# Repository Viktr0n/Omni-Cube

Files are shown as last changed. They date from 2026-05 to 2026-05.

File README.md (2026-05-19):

# Omni-Cube

## Project Overview

The Omni-Cube is a gaming console with an omnidirectional Andotrope display. It is a final thesis project for upper secondary school that addresses the challenge of restricted viewing angles in traditional multiplayer gaming by providing a 360-degree display experience.

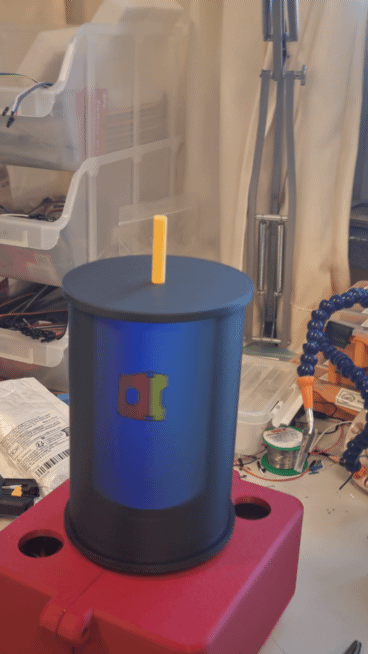
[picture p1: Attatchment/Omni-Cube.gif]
Omni-Cube
 
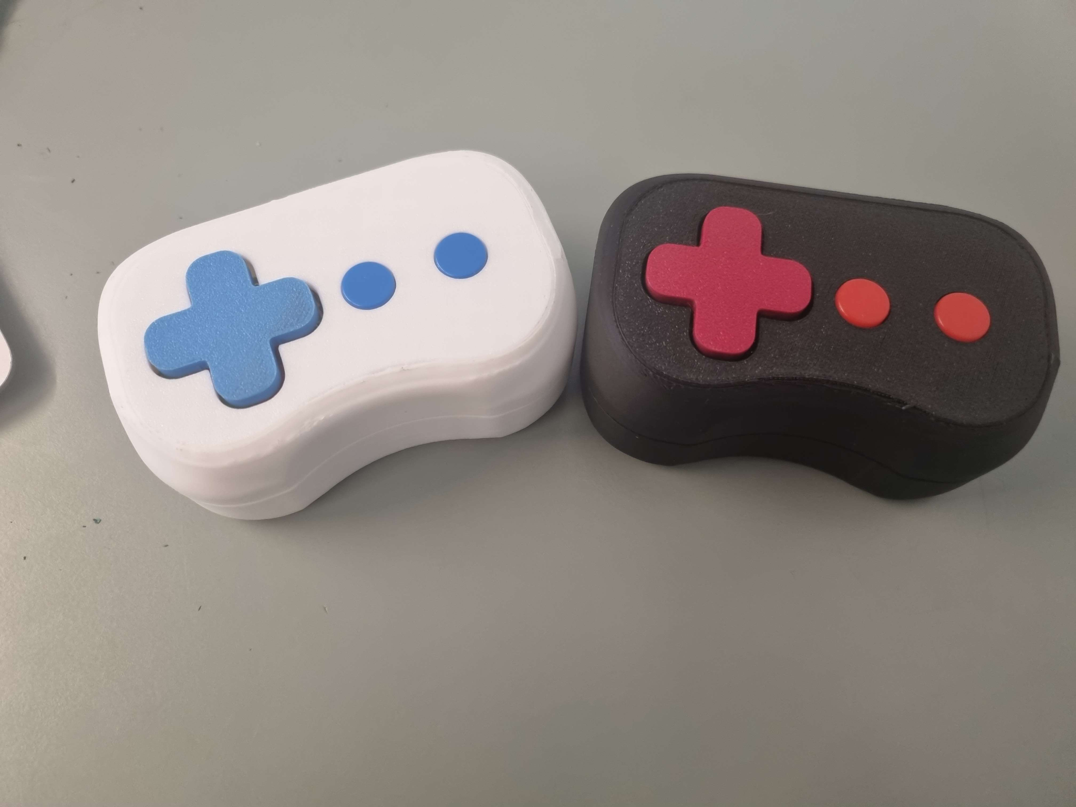
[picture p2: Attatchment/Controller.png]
Controller

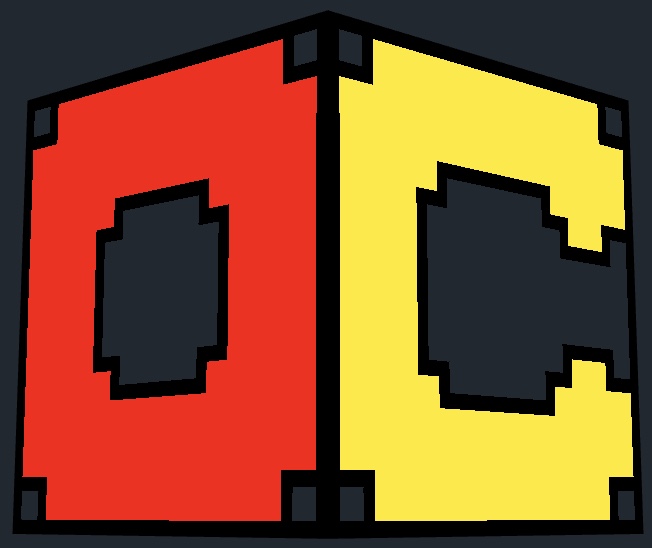
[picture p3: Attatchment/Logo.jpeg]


## Hardware Components

- **Main Console**: Raspberry Pi 3 Model B running CircuitPython
- **Display**: RA8875 omnidirectional display with 360-degree image capability
- **Controllers**: Two handheld wireless controllers built with ESP32/ESP32-S3 using Bluetooth Low Energy (BLE)
- **Motor Control**: H-bridge controlled DC motor for display rotation
- **Chassis**: Custom 3D-printed PLA housing designed in Fusion 360

## Software Structure

- **OC_splashscreen.py** - Splash screen with project title and creator credits
- **OC_main_menu.py** - Main menu system with game selection and power control
- **OC_pong.py** - Pong game implementation with BLE controller support
- **OC_motorCode.py** - Motor control via PWM and GPIO
- **OC_controller_plr1.ino & OC_controller_plr2.ino** - Wireless controller firmware with BLE communication

## Features

- **Dual Wireless Controllers** - D-pad and A/B button inputs for two players
- **BLE Connectivity** - Seamless Bluetooth Low Energy communication between controllers and console
- **Power Management** - Automatic deep sleep modes after 2 minutes of inactivity
- **Expandable Game Architecture** - Easy-to-extend system for adding new games beyond Pong
- **Omnidirectional Display** - 360-degree viewing experience for multiplayer gaming

## Getting Started

The User_manual describes how to start the project, how to maneuver the main menu and the controlls for the Pong game. If you want to add more of your own games to the project, step-by-step instructions are also included in the User_manual

## Authors

- Oscar Bodenäs
- Victor Ekberg

## Technologies

- CircuitPython
- C++ (Arduino)
- Bluetooth Low Energy (BLE)
- RA8875 Display Controller
- Raspberry Pi GPIO Control
- Cad
- Fusion360
- 3DModels
- BambuStudio

## Circuit Diagram

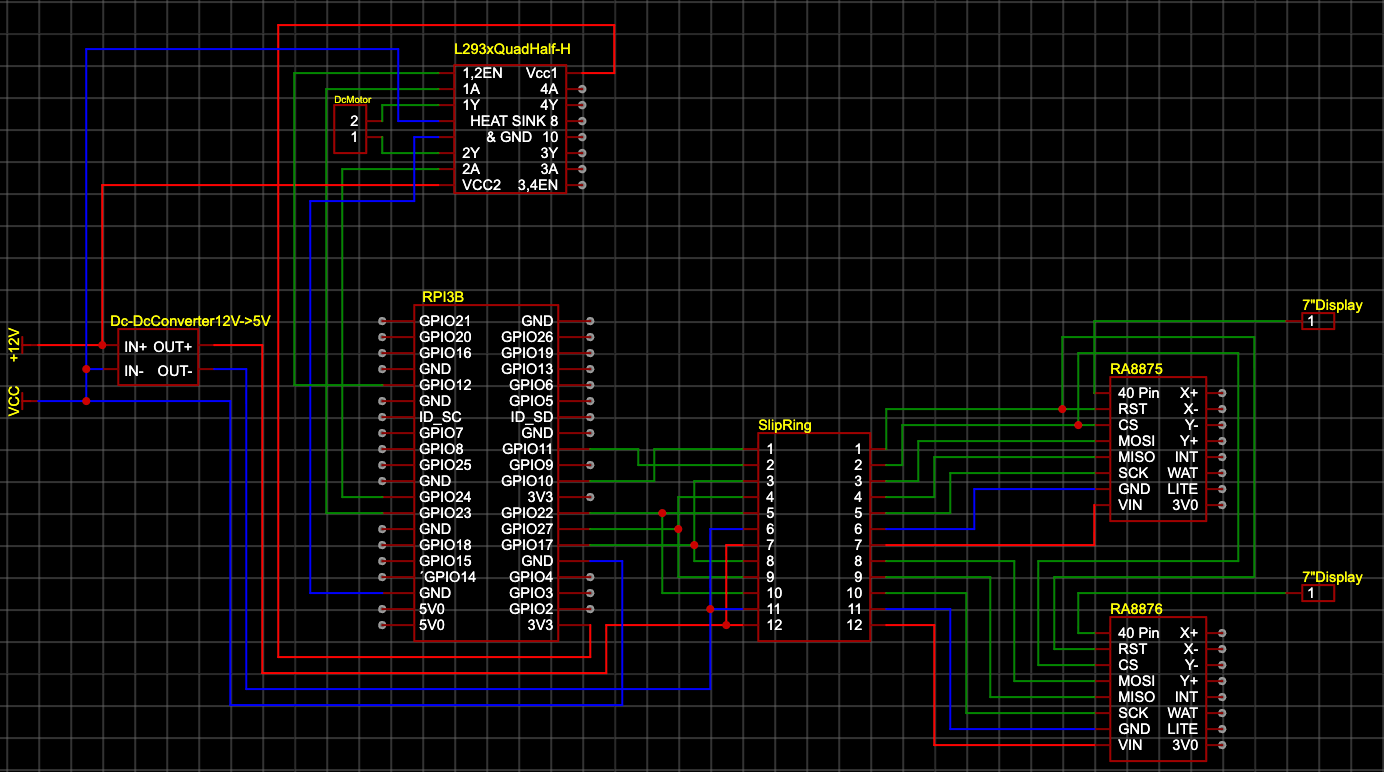
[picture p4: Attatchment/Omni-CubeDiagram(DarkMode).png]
Omni-Cube Diagram

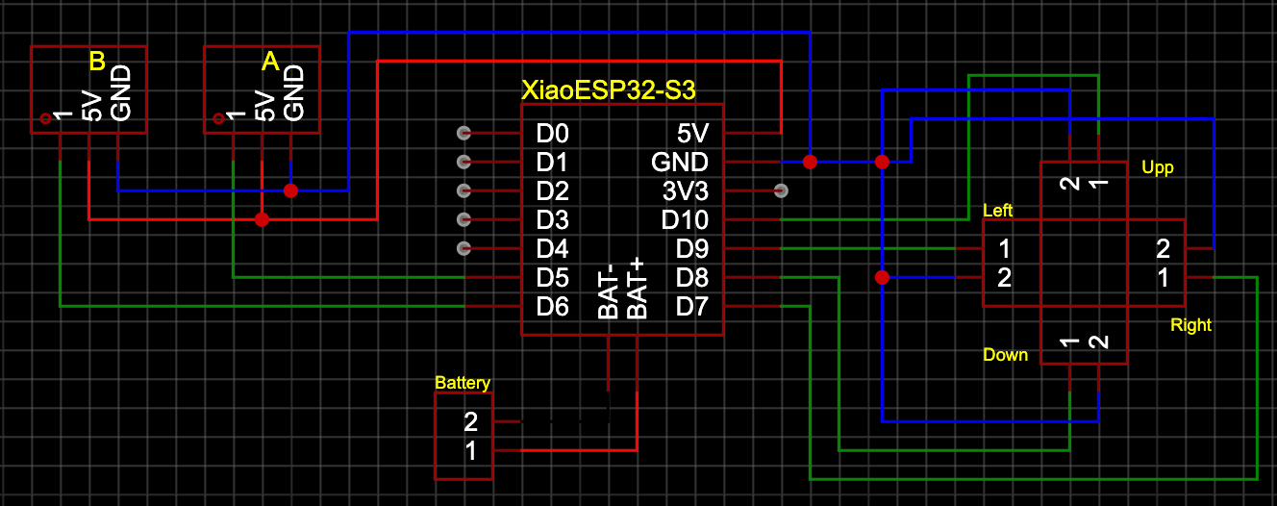
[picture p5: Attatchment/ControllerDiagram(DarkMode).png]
Controller Diagram


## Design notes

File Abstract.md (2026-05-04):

## Abstract

The purpose of this project was to create a gaming console with an omnidirectional screen. Traditional multiplayer gaming often suffers from restricted viewing angles when players are clustered around a single two-dimensional screen. To solve this problem, the Omni-Cube uses an “Andotrope” which is a display visible from 360°. An Andotrope has one or two rotating screens in a cylindrical housing with a slit in. For the display two 7” TFT displays were used with RA8875 as drivers. The Andotrope is driven by a high-torque DC motor. The component that runs the main codes is a Raspberry Pi 3 model B and its code is written in CircuitPython. The Raspberry Pi is mounted on the stationary bottom half of the chassis and needs to be connected with SPI pins to the RA8875 drivers located in the dynamic top half that is continuously rotating. A slipring is used for this. The project also has two controllers that communicate wirelessly with the Raspberry Pi using Bluetooth Low Energy. Both controllers use a Seeed Studio XIAO ESP32-S3 coded with C++ to read the states of the buttons and to connect to the Raspberry Pi via BLE. 

The chassis was designed using Fusion 360 and manufactured via 3D printing with PLA filament to ensure structural integrity. Throughout the development process, significant hardware challenges were addressed, specifically regarding the torque requirements which made it necessary to upgrade the motor, and the initial incompatibility of display drivers which led to the adoption of the RA8875 system.

The Omni-Cube only has one playable game implemented, which is a version of Pong. During the planning phase of the project, more games were planned, but had to be cut from the final version due to time constraints. Despite these constraints, the final prototype successfully demonstrates a stable 360° viewing angle and low-latency wireless controllers. While the hardware functions as intended, some graphical flickering appears due to limitations in the used library, but is not very noticeable due to how the graphics are drawn.

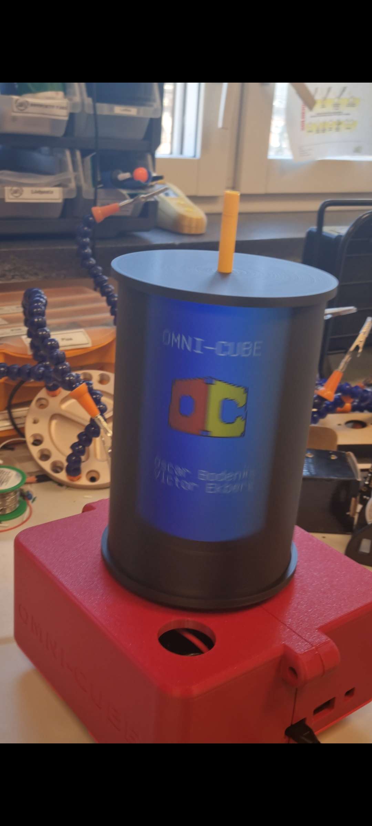
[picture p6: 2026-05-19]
Attatchment/Omni-Cube.jpg

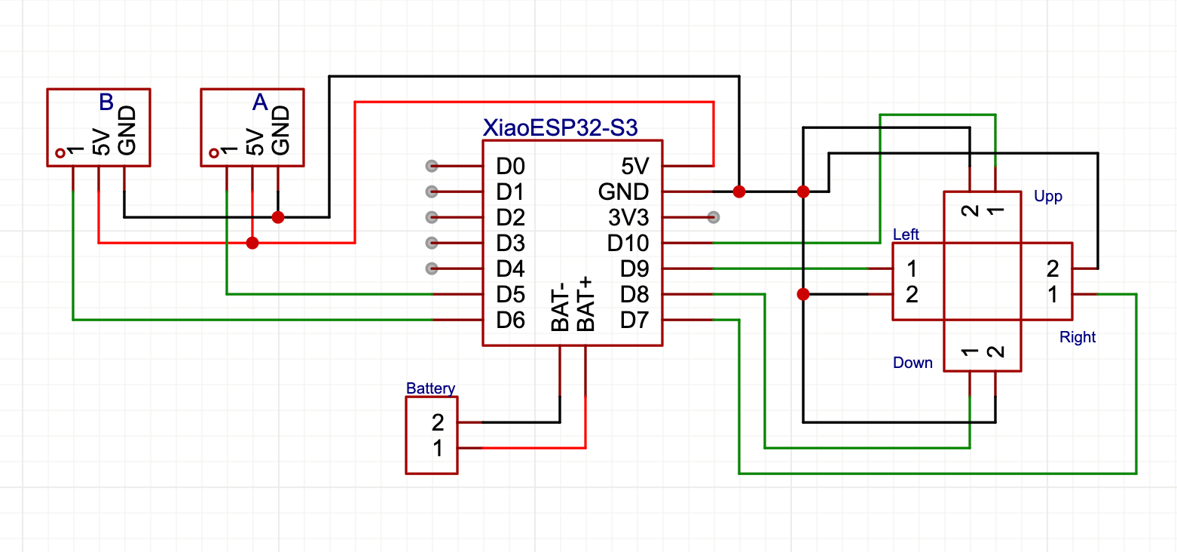
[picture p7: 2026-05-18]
Attatchment/KontrollDiagram.png

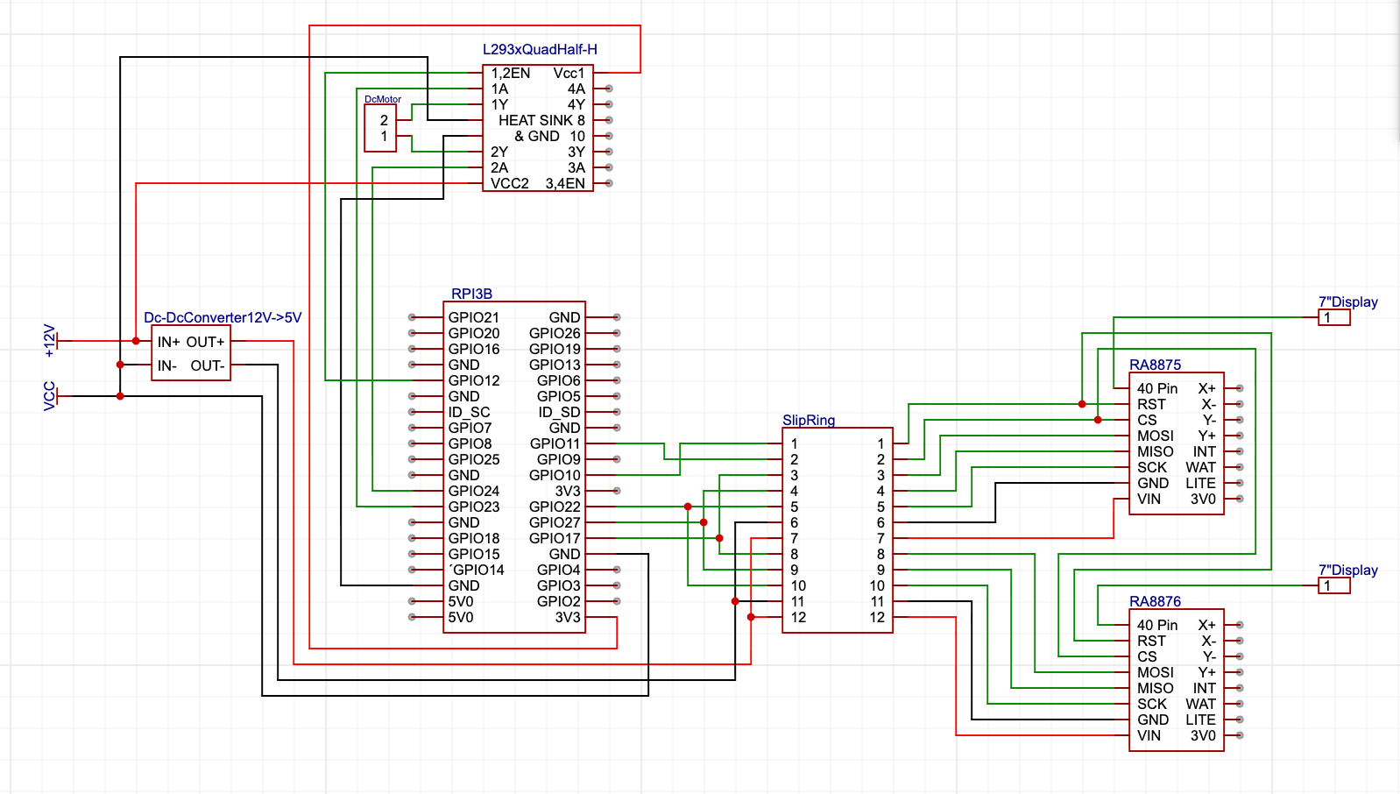
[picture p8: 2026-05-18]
Attatchment/OmniCubeDiagram.png

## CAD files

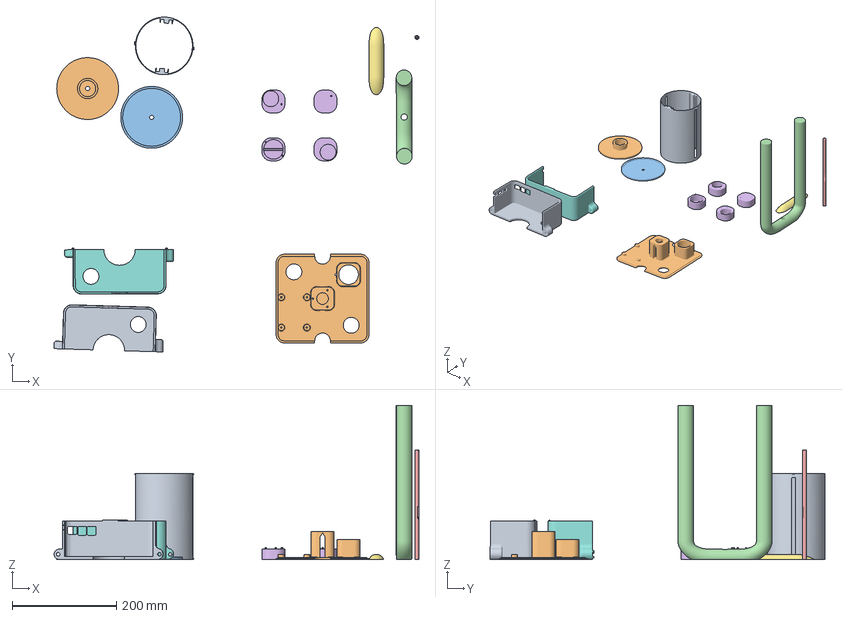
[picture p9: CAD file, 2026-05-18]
3DModels/Omni-CubeFinal.3mf
698.9 x 641.3 x 295.0 mm
Tube
Bottom
Top
Board_B
Shell_B
Shell_A
Board_A

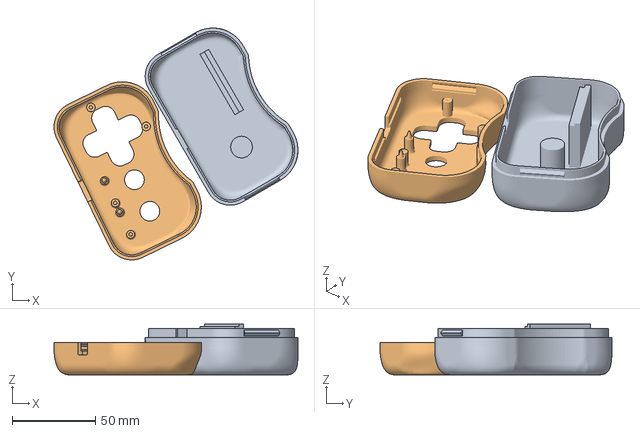
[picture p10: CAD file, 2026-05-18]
3DModels/KontrollFinal.3mf
146.2 x 138.9 x 30.5 mm
Bottom
Top (4)

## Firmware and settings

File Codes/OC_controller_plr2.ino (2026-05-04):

#include <BLEDevice.h>
#include <BLEServer.h>
#include <BLEUtils.h>
#include <BLE2902.h>
#include <BLE2901.h>
#include <cmath>
#include "driver/rtc_io.h"

BLEServer *pServer = NULL;
BLECharacteristic *pCharacteristic = NULL;
BLE2901 *descriptor_2901 = NULL;

bool deviceConnected = false; // Is the device connected

// See the following for generating UUIDs:
// https://www.uuidgenerator.net/
#define SERVICE_UUID        "26478d74-e7d2-48f9-8b20-c10f0fdd20d6"
#define CHARACTERISTIC_UUID "2c8a15df-2c93-4a4b-bb1e-392a74e44864"
#define DEVICE_NAME         "OmnicubePlayer2"

// Button Pins
#define DPAD_UP_PIN D10
#define DPAD_RIGHT_PIN D7
#define DPAD_DOWN_PIN D8
#define DPAD_LEFT_PIN D9
#define BUTTON_B_PIN D6
#define BUTTON_A_PIN D5

unsigned long inactiveMillis; // Milliseconds since last input
unsigned long offMillis; // Millis since last pressing A + B
#define INACTIVE_POWER_OFF 120 // Amount of seconds of inactivity to power off
#define ACTIVE_POWER_OFF 2.5 // Amount of seconds of pushing A + B to power off

// Controller inputs
bool controllerInputsCurrent[6] = {}; // 0 - up, 1 - right, 2 - down, 3 - left, 4 - b, 5 - a
bool controllerInputsOld[6] = {0, 0, 0, 0, 0, 0}; // Used to check for changed inputs

class MyServerCallbacks : public BLEServerCallbacks {
  void onConnect(BLEServer *pServer) { // When connects to RPi, update connection variable
      deviceConnected = true;
  };

  void onDisconnect(BLEServer *pServer) { // If controller disconnects, update connection variable and start advertising
      deviceConnected = false;
      BLEDevice::startAdvertising(); 
  }
};

void ESPSleep(){
  // Enable external wakeup from up button
  esp_sleep_enable_ext0_wakeup((gpio_num_t)DPAD_UP_PIN, 0);
  rtc_gpio_pullup_en((gpio_num_t)DPAD_UP_PIN);
  rtc_gpio_pulldown_dis((gpio_num_t)DPAD_UP_PIN); 

  Serial.flush(); 
  esp_deep_sleep_start(); 
}

void setup() {
  setCpuFrequencyMhz(80); // Set to 80MHz to save power

  // Pin Initialization
  pinMode(DPAD_UP_PIN, INPUT_PULLUP);
  pinMode(DPAD_RIGHT_PIN, INPUT_PULLUP);
  pinMode(DPAD_DOWN_PIN, INPUT_PULLUP);
  pinMode(DPAD_LEFT_PIN, INPUT_PULLUP);
  pinMode(BUTTON_A_PIN, INPUT_PULLUP);
  pinMode(BUTTON_B_PIN, INPUT_PULLUP);
  
  // BLE Setup
  BLEDevice::init(DEVICE_NAME);

  // Create the BLE Server
  pServer = BLEDevice::createServer();
  pServer->setCallbacks(new MyServerCallbacks());

  // Create the BLE Service
  BLEService *pService = pServer->createService(SERVICE_UUID);

  // Create a BLE Characteristic
  pCharacteristic = pService->createCharacteristic(
    CHARACTERISTIC_UUID,
    BLECharacteristic::PROPERTY_READ | BLECharacteristic::PROPERTY_WRITE | BLECharacteristic::PROPERTY_NOTIFY | BLECharacteristic::PROPERTY_INDICATE
  );

  // Creates BLE Descriptor 0x2902: Client Characteristic Configuration Descriptor (CCCD)
  pCharacteristic->addDescriptor(new BLE2902());

  pService->start();

  // Advertising setup, Start advertising
  BLEAdvertising *pAdvertising = BLEDevice::getAdvertising();
  pAdvertising->addServiceUUID(SERVICE_UUID);
  pAdvertising->setScanResponse(true); // Changed to true to help discovery
  pAdvertising->setMinPreferred(0x06);  
  pAdvertising->setMaxPreferred(0x12);
  BLEDevice::startAdvertising();
}

void loop() {
  bool inputs_changed = false; // Has inputs changed?
  int data_to_send = 0;

  // Read Sensors. Inverted because of buttons being active low
  controllerInputsCurrent[0] = !digitalRead(DPAD_UP_PIN);
  controllerInputsCurrent[1] = !digitalRead(DPAD_RIGHT_PIN);
  controllerInputsCurrent[2] = !digitalRead(DPAD_DOWN_PIN);
  controllerInputsCurrent[3] = !digitalRead(DPAD_LEFT_PIN);
  controllerInputsCurrent[4] = !digitalRead(BUTTON_B_PIN);
  controllerInputsCurrent[5] = !digitalRead(BUTTON_A_PIN);

  if(!controllerInputsCurrent[4] + !controllerInputsCurrent[5]){ // If A + B is not pressed, update offMillis
    offMillis = millis();
  }

  for(int i = 0; i <= 5; i++){ // Check for Changes
    if(controllerInputsCurrent[i] != controllerInputsOld[i]){
      inputs_changed = true;
    }
    controllerInputsOld[i] = controllerInputsCurrent[i];
  }

  if (inputs_changed) { // Send data if inputs changed
    inactiveMillis = millis(); // Update time since last input
    for(int i = 0; i <= 5; i++){ // Format the data into an int (eg 010011 would be up + right + b)
      data_to_send += controllerInputsCurrent[i] * pow(10, i);
    }
    if (deviceConnected) {//Sends data
      pCharacteristic->setValue((uint8_t *)&data_to_send, 4);
      pCharacteristic->notify();
    }
  }
  
  if(millis()-offMillis > ACTIVE_POWER_OFF * 1000 || millis()-inactiveMillis > INACTIVE_POWER_OFF * 1000){
    ESPSleep();
  }
}
